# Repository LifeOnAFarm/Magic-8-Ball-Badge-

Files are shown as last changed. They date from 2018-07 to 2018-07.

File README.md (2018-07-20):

# Magic 8-Ball Badge 
Created in the lead up to DefCon 26 #BadgeLife

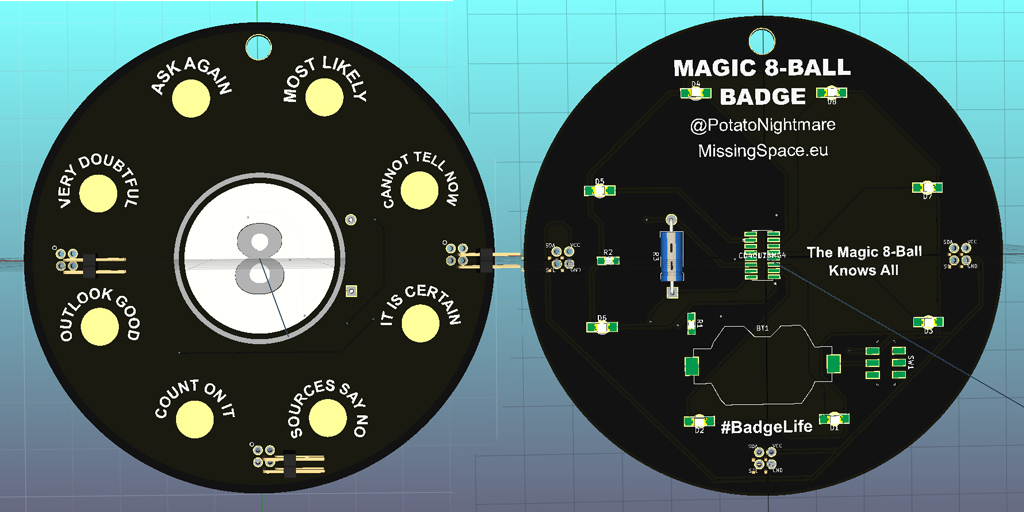
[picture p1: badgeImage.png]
BadgeImage


## Getting Started

Welcome to the Magic 8-Ball Badge files/guide.

Here you will find a svg image of the PCB and all the schematics, gerbers and Kicad files you need to make your own Magic 8-Ball Badge. I recommend @MrTwinkleTwink's video on how to convert svg images to Kicad files using Inkscape if you want to make any board chances (https://youtu.be/61NFK9KW).
  
First off, as a warning, I'm by no stretch of the imagination a professional PCB designer and while I have tested the circuit on a similar project I've yet to receive and test this PCB (Will update when I do). Make sure to check through the schematics and make any changes you feel fit (and try not to have an aneurysm when you look at my wiring).

## Quirks:

There are a few quirks to this board. One ~~flaw~~ feature is that the switch doesn't power the PCB on and off, but switches the power from the 8-Ball circuit to the Shitty Add-On headers. Another quirk you might notice in Kicad, is that I couldn't find the footprint for a SW-200D tilt switch so I just used a similar sized component.

## Components You Will Need:

- 1 x SW-200D Tilt Switch

- 3 x 0.1" 2x2 Female Headers

- 8 x 1206 LEDS (Solder these with the top of the LED facing towards the PCB board)

- 1 x Keystone 1058 2032 Coincell Battery Holder

- 1 x CD4017BM Decade counter

- 1 x 0805 10K Resistor

- 1 x 0805 220 Resistor

- 1 x Switch Slide JS202011SCQN 

## Authors

- Seamus de Cleir (@PotatoNightmare)

## License

This project is licensed under the MIT License. 

All I ask is that you leave my Twitter handle on the back of the board, thanks. - see the LICENSE.md file for more details

## Acknowledgments

@MrTwinkleTwink for the great tutorial on SAO's 

## Donations

A button to buy me a cup of coffee if you see fit



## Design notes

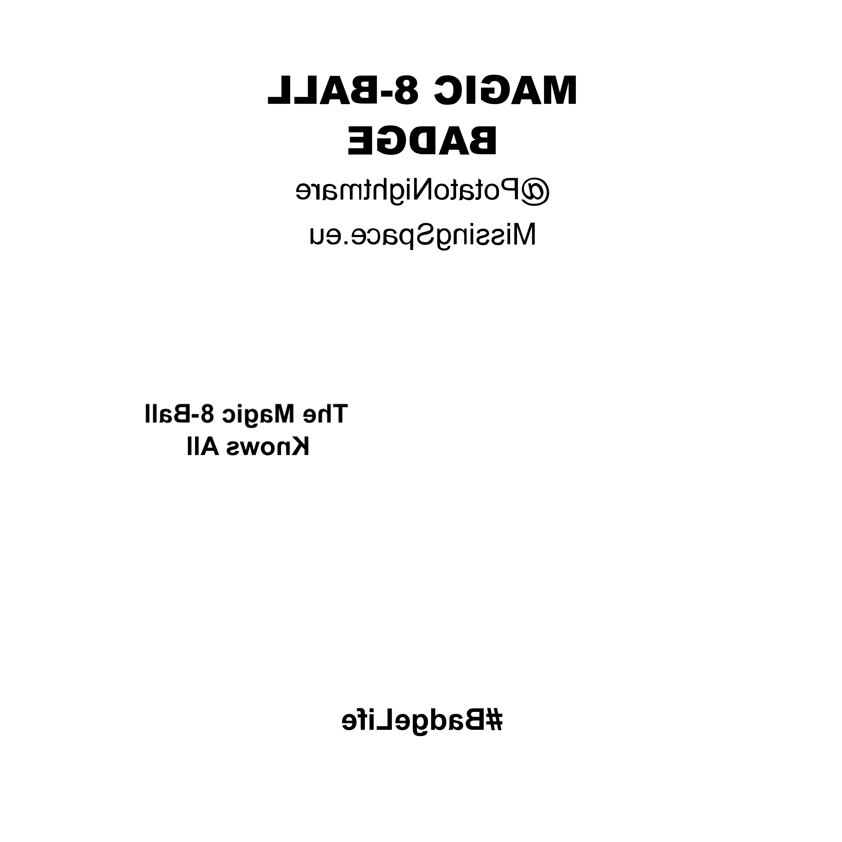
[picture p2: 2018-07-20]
.svg2shenzhen-cache/images/B.Silk_g707.png

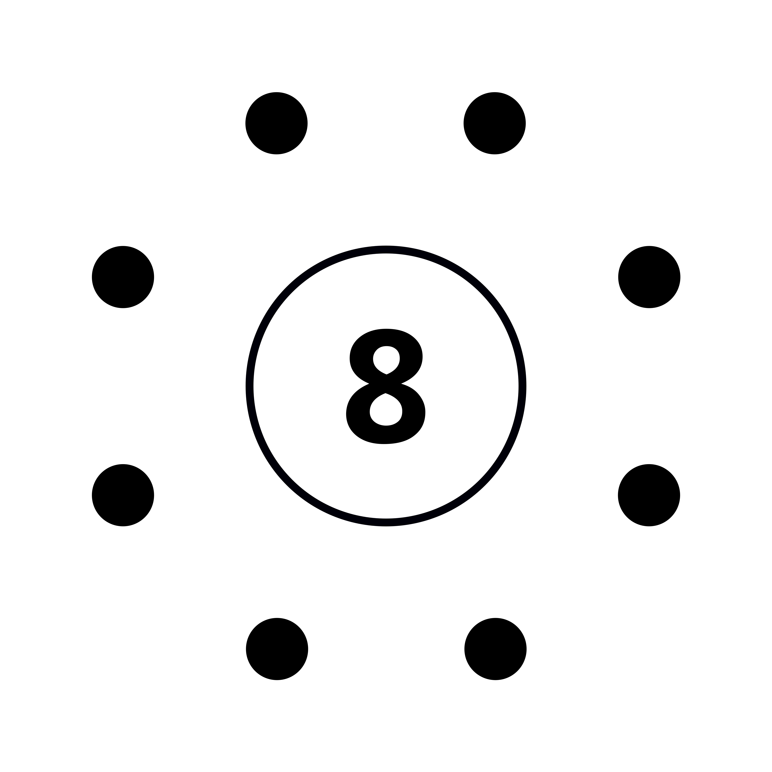
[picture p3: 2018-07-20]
.svg2shenzhen-cache/images/F.Mask_g711.png

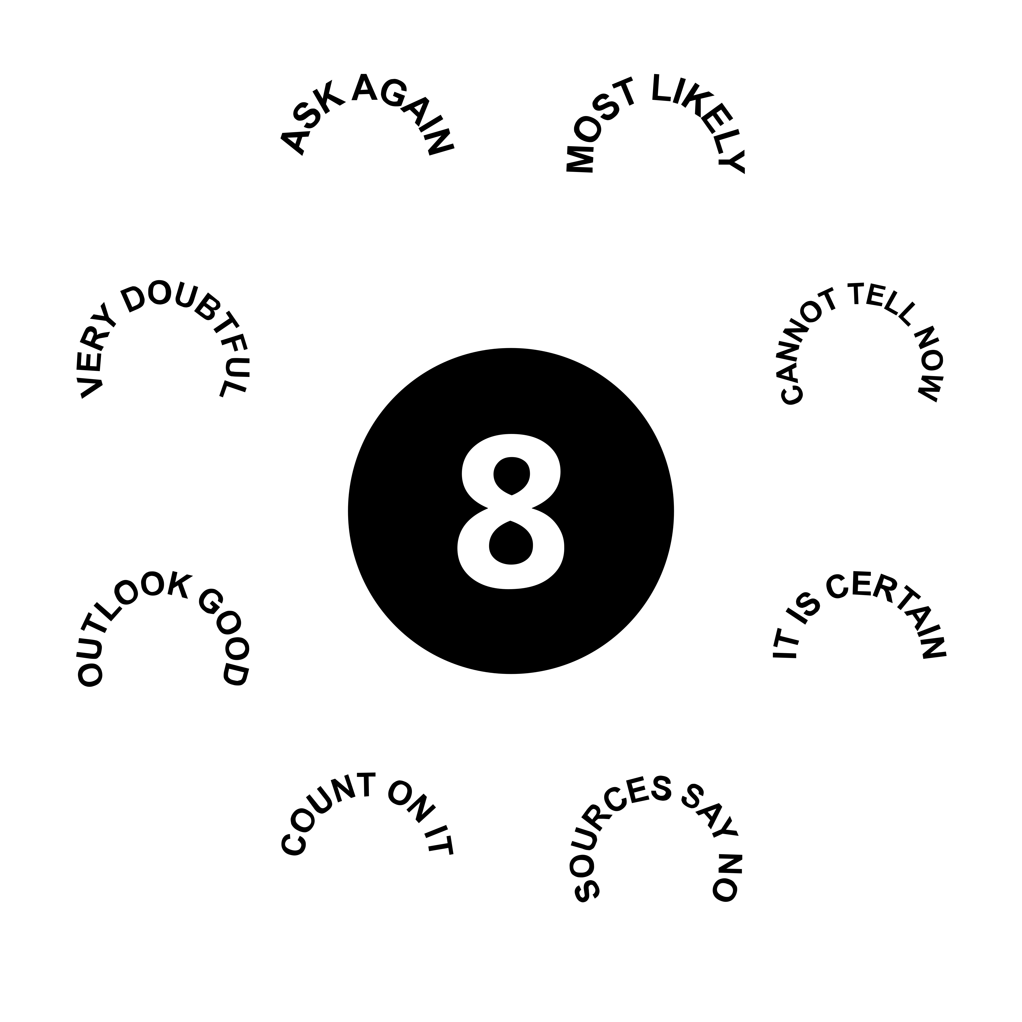
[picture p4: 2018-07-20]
.svg2shenzhen-cache/images/F.Silk_g713.png

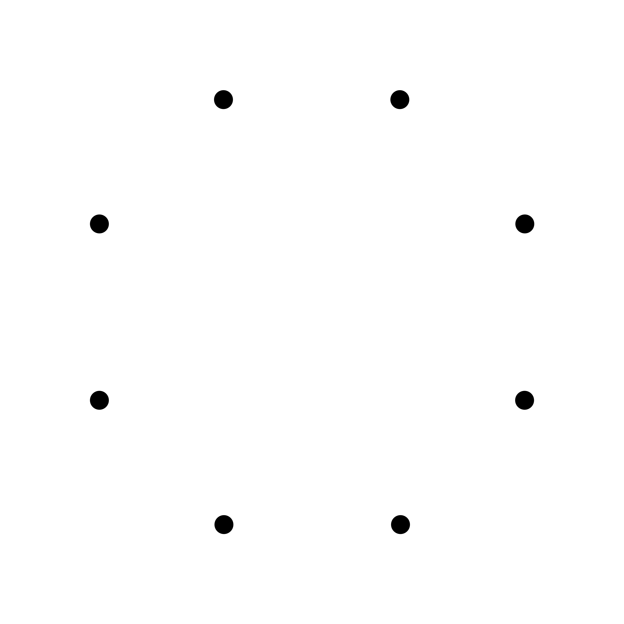
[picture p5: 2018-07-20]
.svg2shenzhen-cache/images/B.Mask_g705.png

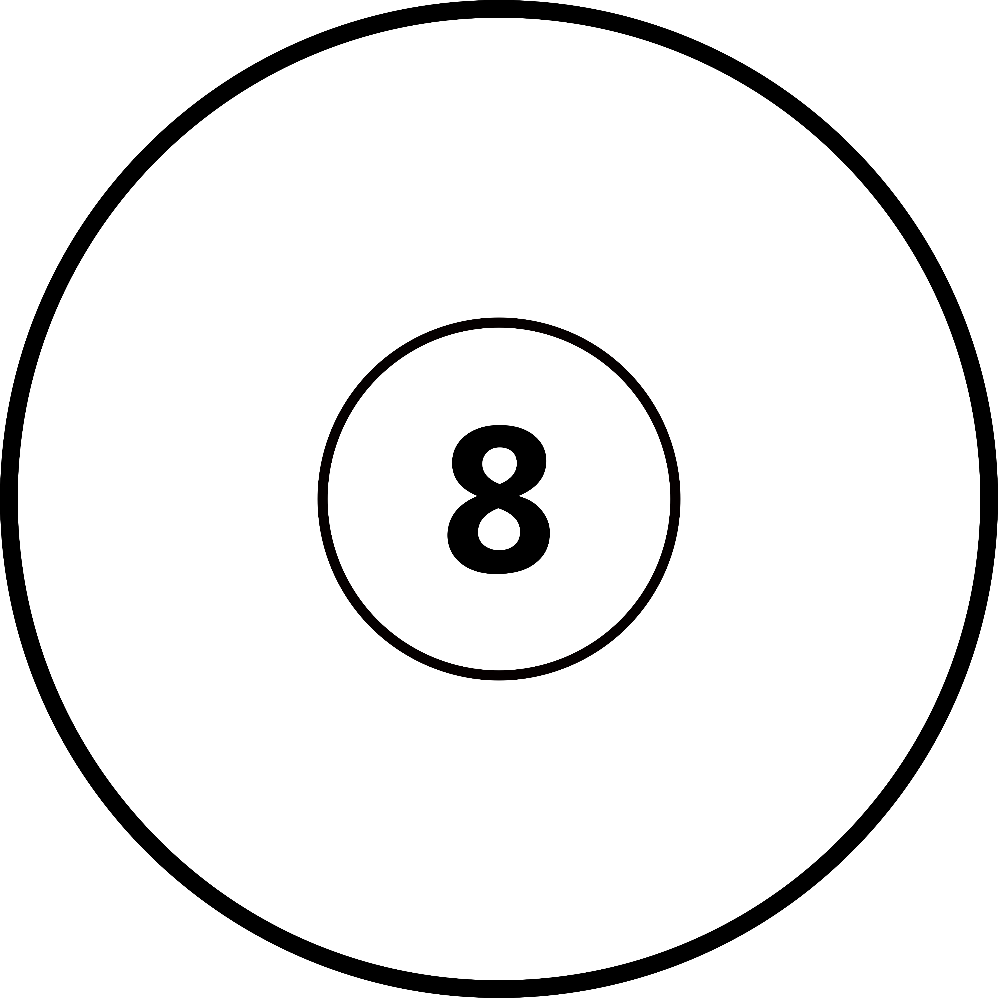
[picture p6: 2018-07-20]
.svg2shenzhen-cache/images/F.Cu_g709.png

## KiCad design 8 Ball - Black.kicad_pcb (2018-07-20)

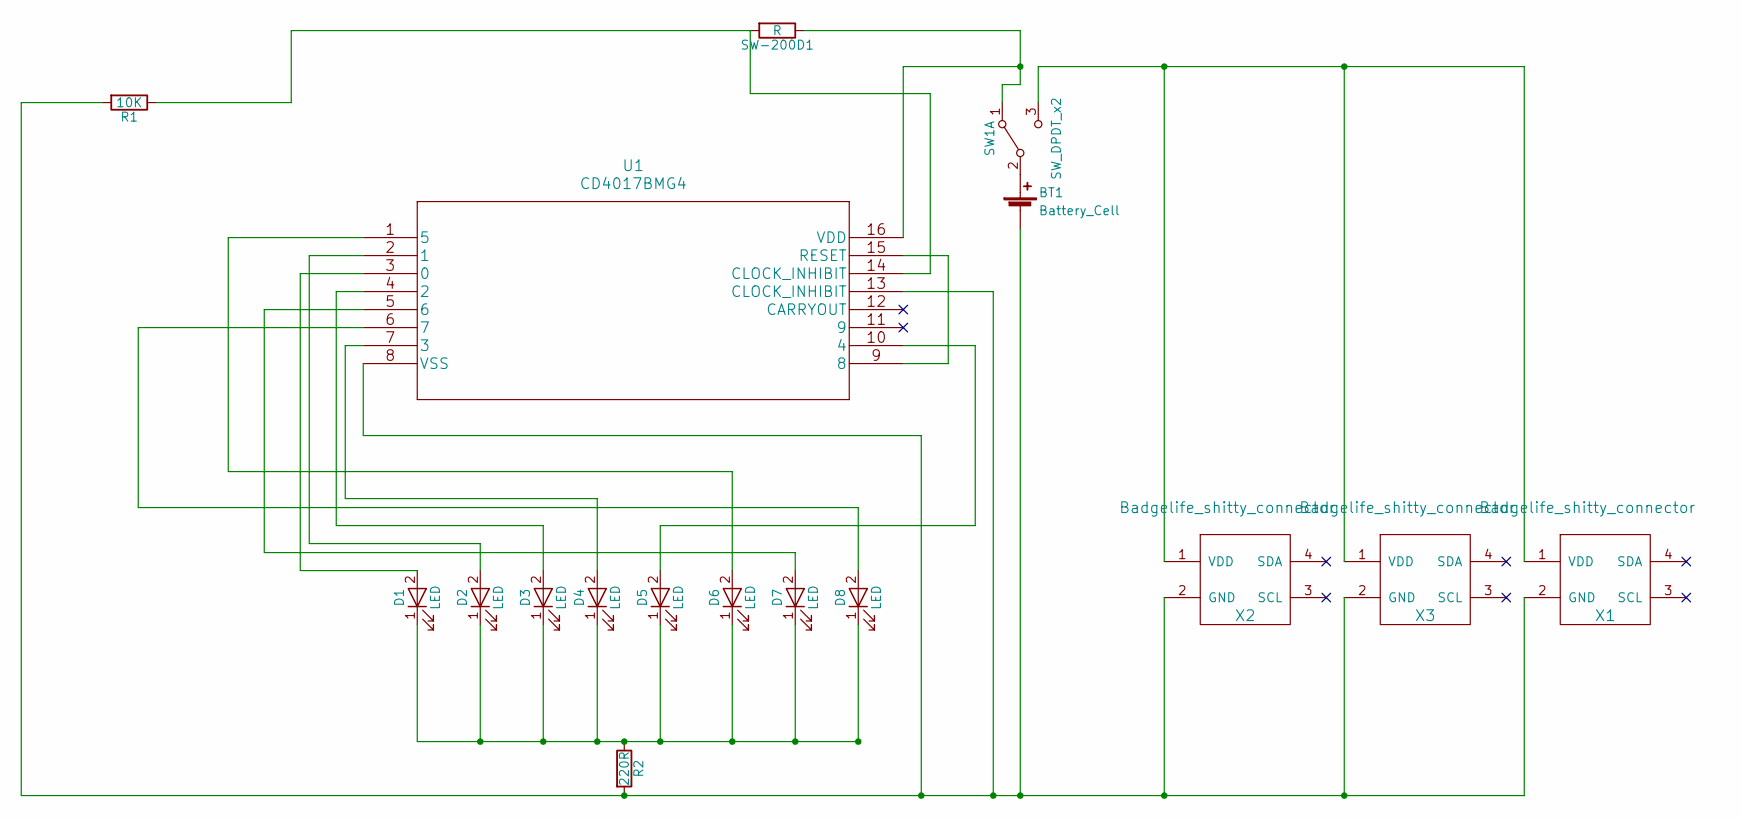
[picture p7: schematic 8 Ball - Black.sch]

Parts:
BT1: Battery_Cell; Keystone_1058_1x2032-CoinCell
D1, D2, D3, D4, D5, D6, D7, D8: LED; LED_1206_HandSoldering
R1: 10K; LED_0805_HandSoldering
R2: 220R; LED_0805_HandSoldering
SW1: SW_DPDT_x2; Switch_Slide_JS202011SCQN
SW-200D1: R; CP_Axial_L10.0mm_D4.5mm_P15.00mm_Horizontal
U1: CD4017BMG4; CD4017BM96
X1, X2, X3: Badgelife_shitty_connector; Badgelife-Shitty-2x2

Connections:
unnamed: BT1.1 (+), SW1.2 (B)
unnamed: BT1.2 (-), R1.2, R2.2, U1.8 (VSS), U1.13 (CLOCK_INHIBIT), X1.2 (GND), X2.2 (GND), X3.2 (GND)
unnamed: D1.1 (K), D2.1 (K), D3.1 (K), D4.1 (K), D5.1 (K), D6.1 (K), D7.1 (K), D8.1 (K), R2.1
unnamed: D1.2 (A), U1.3 (0)
unnamed: D2.2 (A), U1.2 (1)
unnamed: D3.2 (A), U1.4 (2)
unnamed: D4.2 (A), U1.7 (3)
unnamed: D5.2 (A), U1.10 (4)
unnamed: D6.2 (A), U1.1 (5)
unnamed: D7.2 (A), U1.5 (6)
unnamed: D8.2 (A), U1.6 (7)
unnamed: R1.1, SW-200D1.2, U1.14 (CLOCK_INHIBIT)
unnamed: SW1.3 (C), X1.1 (VDD), X2.1 (VDD), X3.1 (VDD)
unnamed: SW1.1 (A), SW-200D1.1, U1.16 (VDD)
unnamed: U1.9 (8), U1.15 (RESET)

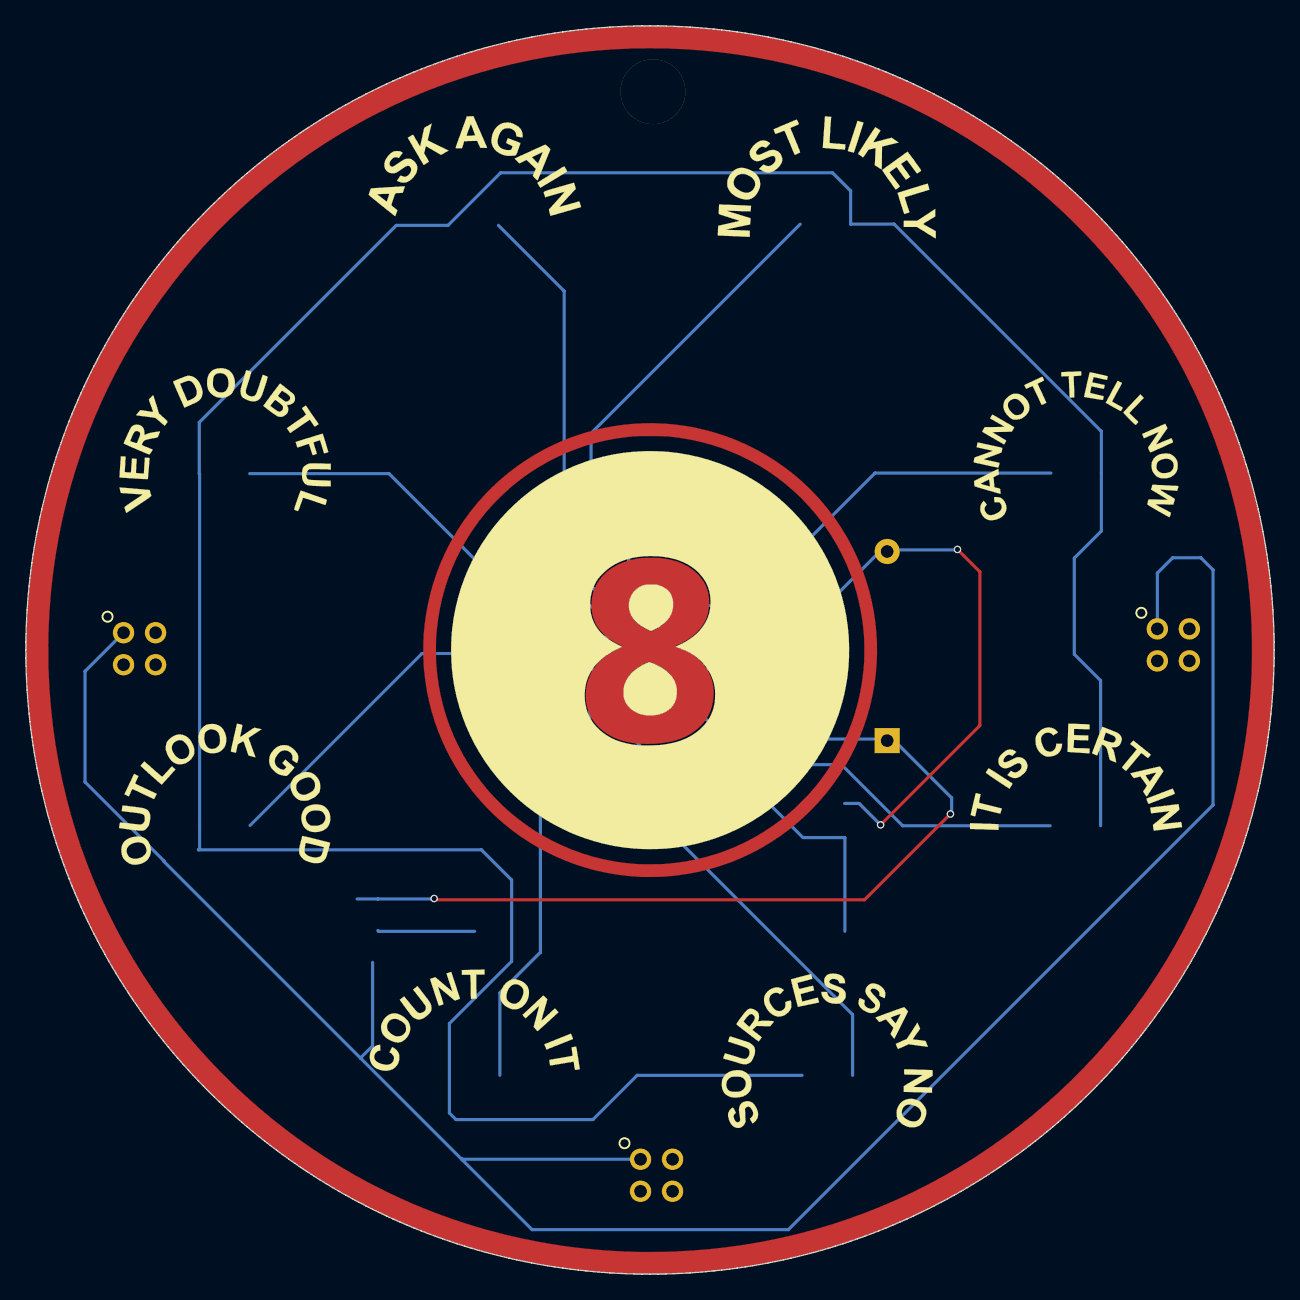
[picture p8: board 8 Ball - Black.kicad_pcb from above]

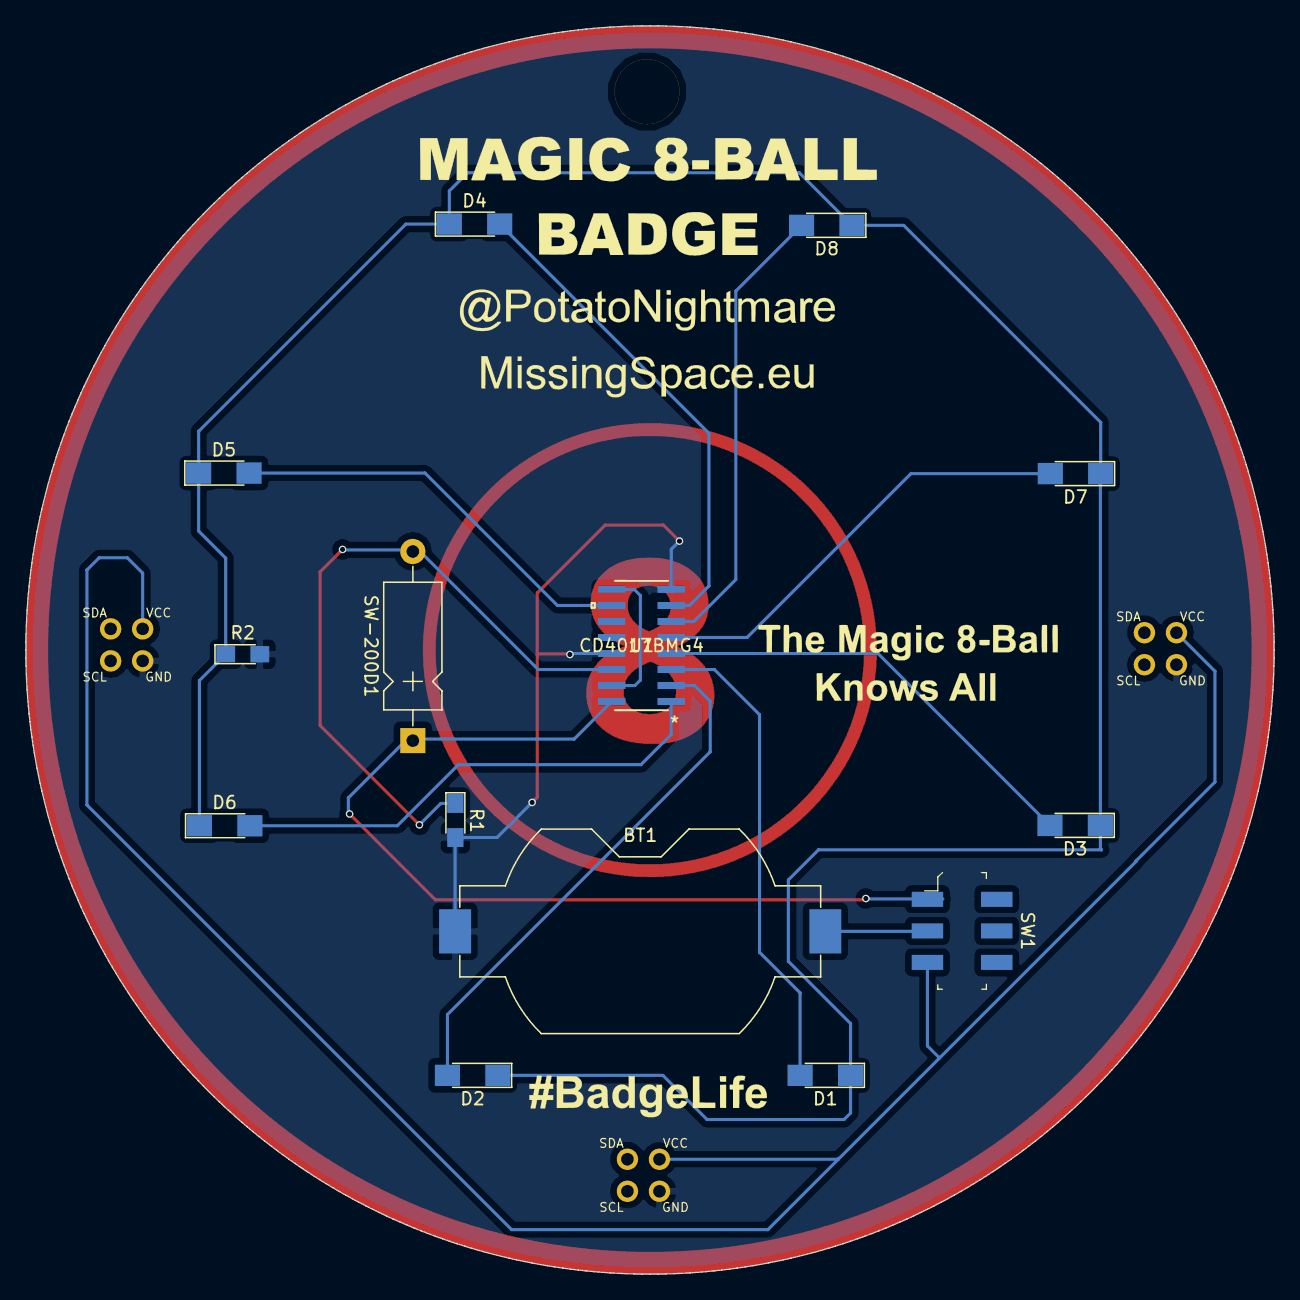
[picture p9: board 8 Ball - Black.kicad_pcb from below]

Board: 2 copper layers, 99.0 x 99.0 mm, 17 parts (14 on the bottom side), 15 nets.

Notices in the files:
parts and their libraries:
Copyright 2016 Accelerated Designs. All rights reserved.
